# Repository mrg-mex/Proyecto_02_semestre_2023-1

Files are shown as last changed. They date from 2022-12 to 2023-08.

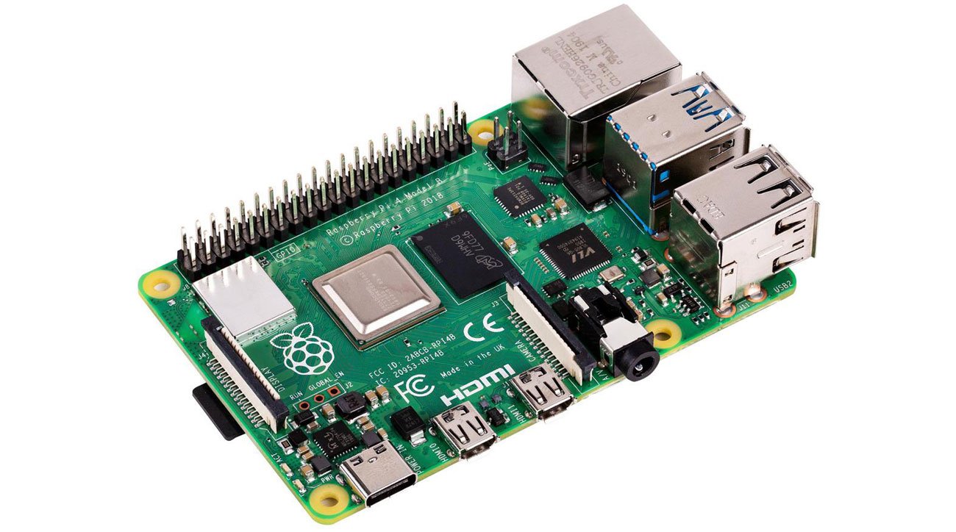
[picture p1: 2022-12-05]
CAD/Raspberry/Raspberry_Pi_4_model_B_widok_ogolny_1.jpg

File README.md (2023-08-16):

# Proyecto_2_semestre_2023-1
# Revisión, rediseño e implementación de un robot móvil Rasbot UNAM

# Participantes
- Erik Peña Medina (responable).
- Rojas Trejo Sebastián (participante)
- Luis García Mejía (participante)
- Andrés David Flores Ferro (participante)
- Alvarado Rivera Daniela (Participante, Semestre 2023-2)
- García Ávila Angel Alberto (Participante, Semestre 2023-2)
- Rios Torres Brenda (Participante, Semestre 2023-2)

# Contenido
- [Objetivo](https://github.com/mrg-mex/Proyecto_02_semestre_2023-1/blob/main/README.md#objetivo)
- [Metas](https://github.com/mrg-mex/Proyecto_02_semestre_2023-1/blob/main/README.md#metas)
- [Productos](https://github.com/mrg-mex/Proyecto_02_semestre_2023-1/blob/main/README.md#productos)
- [Introducción](https://github.com/mrg-mex/Proyecto_02_semestre_2023-1/blob/main/README.md#introducci%C3%B3n)
- [Desarrollo](https://github.com/mrg-mex/Proyecto_02_semestre_2023-1/blob/main/README.md#desarrollo)
- [Conclusión](https://github.com/mrg-mex/Proyecto_02_semestre_2023-1/blob/main/README.md#conclusi%C3%B3n)

# Objetivo

Implementar un robot móvil (2,0) el cual podrá ser utilizado para la programación de algoritmos de navegación mediante el uso de sensores ultrasónicos y análisis de imágenes.

# Metas

-	Evaluar y rediseñar el diseño del robot móvil con el fin de incorporar un par de sensores ultrasónicos y el controlador de los motores.
-	Desarrollar una simulación del robot móvil Gazebo como herramienta de integración en ROS2.
-	Implementar los resultados de la simulación en un ambiente físico definido para los robots.

# Productos

- Un banco de pruebas virtual en el cual se pueden programar diferentes algoritmos de navegación en el robot móvil. 
- Un banco de pruebas físico en el cual puedan ser implementados los algoritmos comprobados en el banco de pruebas virtual.
- Un repositorio con todos los archivos generados durante el desarrollo del proyecto.
- Circuito físico del sensor HY-SRF05
-	Circuito físico de dos motorreductores controlados con un controlador
-	Cámara Raspberry Pi NoIR Camera V2 funcionando adecuadamente

# Introducción
El desarrollo de los robots móviles ocurre debido a la necesidad de realizar cierto tipo de movimientos en ambientes determinados, de los cuales se desea obtener información mediante sensores que ayuden a medir las variables de interés (distancia, velocidad, humedad, etc.).

Ante la emergencia sanitaria que se vivió en el año 2020 (COVID 19), la robótica móvil comenzó a desarrollarse aún más, esto, debido a que era necesario reducir el contacto humano. Un gran ejemplo de esto ocurrió en la clínica Victoria de Medellín ubicada en Colombia, en donde se implementó un robot móvil para esterilizar espacios que habían sido contaminados de manera rápida y efectiva sin la necesidad de que hubiera contacto físico. En la India también se pudo observar que había robots móviles encargados de suministrar alimento y medicamentos a pacientes con COVID 19, esto ayudaba a minimizar el contagio, pues era como si los pacientes fuesen prácticamente independientes de otros seres humanos.

Lo anterior significa que existe un gran campo de aplicación de los robots móviles, e incluso hay necesidades que aún no están cubiertas porque no hay situación que lo amerite, pero la tecnología debe estar preparada para enfrentar cualquier situación que surja en el mundo.
Un robot móvil es capaz de moverse autónomamente y de ejecutar determinadas acciones. Junto a la movilidad, por tanto, la independencia del robot respecto de la intervención humana es uno de los aspectos esenciales de la robótica móvil.

La robótica móvil actualmente aún se encuentra en un estadio relativamente temprano de su desarrollo, hace varios años que se utilizan prototipos y productos en serie en diferentes sectores como en el transporte, la agricultura, vehículos autónomos, etc.

Algunas de las características que presenta la robótica móvil son:
- Percepción mediante sistemas sensores
- Capacidad de adaptación ante circunstancias espaciales modificadas
- Navegación, planificación y actuación autónomas
- Software/programación orientados a tareas 

Por medio de este documento se intenta plasmar algunas situaciones de diseños que se solucionaron en el robot raspbot como lo es el redimensionamiento de algunas piezas, la corrección de problemas al abrir archivos en solidworks, el diseño y ensamble de nuevas piezas, entre otras actividades que se especificaran en el documento.

Lo anterior se planteó solucionar mediante la separación de actividades usando issues y mediante el uso del programa solidworks y finalmente los resultados obtenidos se encuentran descritos a lo largo de documento.

# Desarrollo

Las problemáticas del robot móvil (2,0) comenzaron con la presencia de errores en los archivos Chasis_2-1 y Chaster_shorun_65-1 provenientes del ensamble CAD, siendo la pieza de chasis del robot y la pieza del sistema de rueda bola loca respectivamente. Por lo tanto este fue el primer problema que se atacó y por ende el primero que se resolvió, siendo de vital importancia para el correcto desarrollo del proyecto debido a que bajo éste ensamble y sus archivos, trabajaría todo el equipo.

Al tener un ensamble libre de errores, procedimos a identificar, estructurar, organizar y delimitar tareas por medio de problemáticas o issues usando GitHub como herramienta. Identificamos y propusimos en total seis problemas principales en cuanto a diseño se refiere:

- [Actividad 1: Arreglar archivos actuales que originan errores de ensamble.](https://github.com/mrg-mex/Proyecto_02_semestre_2023-1/issues/1)
- [Actividad 2: Diseño colocación del sistema de sensores ultrasónicos.](https://github.com/mrg-mex/Proyecto_02_semestre_2023-1/issues/2)
- [Actividad 3: Cambio diseño superior de robot móvil, NUEVO Ventilador para Raspberry.](https://github.com/mrg-mex/Proyecto_02_semestre_2023-1/issues/3)
- [Actividad 4: Modificaciones en chasis para problemáticas actuales.](https://github.com/mrg-mex/Proyecto_02_semestre_2023-1/issues/4)
- [Actividad 5: Detalles para base superior código QR.](https://github.com/mrg-mex/Proyecto_02_semestre_2023-1/issues/5)
- [Actividad 6: Recuperar diseño actual de pieza. Rueda bola loca.](https://github.com/mrg-mex/Proyecto_02_semestre_2023-1/issues/6)

En base a estas problemáticas y con la primera de ellas ya resuelta (arreglo de archivos) distribuimos las problemáticas entre los tres integrantes de este proyecto para así, lograr un mayor avance en la solución y conclusión de la lista de problemas; sin dejar de lado una comunicación entre los integrantes del equipo ante cualquier situación o solicitud de apoyo.

Para iniciar nuestras respectivas actividades, lo primero que se hizo fue analizar el robot móvil físicamente para anotar dimensiones, observar los elementos que los componen y su distribución, ver los espacios o secciones no aprovechadas en el chasis y su factibilidad de realizar modificaciones en ese espacio específico. Esto nos brindó mucha información en nuestra lluvia de ideas para lograr la solución más creativa y óptima. Asimismo, aprovechamos para tomar las medidas correctas principalmente de la rueda bola loca, siendo un proceso esencial en la actividad 6 para comparar las medidas reales con las medidas establecidas en el CAD y modificarlas a su valor real. De manera secundaria, se observó y midió el ventilador para la Raspberry con fines de lograr una eficaz modificación en la parte superior del robot. Finalmente pero no menos importante, se observó el modelo para obtener ideas acerca de la colocación de tres sensores ultrasónicos y el doble puente H que llevará el robot para el control de los dos motores CD.

Las modificaciones al chasis del robot móvil fueron una parte vital de nuestro proyecto, ya que ésta actividad tenía relación con la base superior, las conexiones con el microprocesador Raspberry y el doble puente H y la colocación de los sensores ultrasónicos, por ende, las primeras modificación que se hicieron fueron en beneficio de la óptima conexión entre la Raspberry y el doble puente H, y modificaciones para la colocación de la base superior.

Para la base superior, se modificaron los diámetros de los orificios donde se insertan los postes de latón que sujetan a la Raspberry y se extruyeron un par de milímnetros más para aumentar la altura de la base y así liberar la entrada micro SD. Para garantizar que el usuario que maneje el robot móvil no tenga problemas con la inserción y retiro de la micro SD, los orificios se separaron ligeramente de la base para la cámara.

Las siguientes modificaciones a trabajar fueron los elementos para la conexión del microcontrolador y el puente H. Dicha conexión se logró perforando en forma de ranura el lateral del chasis para que, de esta manera los cables que deriven de la Raspberry puedan pasar por esta ranura y no dificulte el desplazamiento del robot. Para la colocación del doble puente H se realizó una serie de canales o correderas, en donde se deslizará y sujetará el módulo con los pines disponibles para conexión. Como complemento, se realizó un arco en el lateral del chasis, cerca de la ranura con el fin de que por ahí pasen los cables de conexión y se contengan dentro del arco, evitando que los cables sobresalgan demasiado y estorben en su funcionamiento más de lo que ayudan.




La última modificación para el chasis dependía del diseño previo realizado para la colocación de los tres sensores ultrasónicos. Se llegó a un primer modelo, el cual, después de ser analizado y ensamblado a la estructura, se desechó debido al sesgo y posibles errores de sensado debido a la distribución propuesta.



Procedimos a realizar una segunda propuesta, donde dos de los sensores ultrasónicos estarán en la parte superior del chasis a los laterales y el tercero se encontrará enfrente de éste, en la parte inferior, haciendo analogía a una defensa de auto. La estructura para la colocación de los dos sensores laterales estará integradas directamente al chasis, mientras que el tercero se montará con ayuda de una pieza externa. Con estos requerimientos y consideraciones, procedimos a modificar el chasis con las operaciones oportunas para lograr el correcto ensamble y montaje de los tres sensores, solucionando así la actividad 2 y 4



Para la solución de la actividad 3 (el ventilador), se encontró un CAD existente con las dimensiones requeridas, se colocó en el CAD e implementaron restricciones para mantenerlo en el lugar adecuado dentro del archivo de ensamble y finalmente se modificó la base para lograr una disminución de espacio.



La actividad 5, al estar relacionada de igual manera con la base (la cual fue modificada en la actividad 3), logró solucionarse de una manera más sencilla con el acomodo del ventilador y la base del código QR.



Para la actividad 6 bastó con modificar los elementos que componían la rueda bola loca y ajustarlos a las medidas reales realizadas en el laboratorio.



De esta forma se concluyeron exitosamente las actividades propuestas al inicio del proyecto, logrando obtener un archivo ensamble completo, que inmediatamente se mandó a imprimir para observar y probar los resultados finales de nuestro trabajo. Sin embargo, esto no fue posible debido a un problema con la boquilla en la impresora 3D, dificultando la salida del material para la fabricación el chasis. 

Finalmente se decidió que la mejor solución será cambiar la boquilla por una nueva y mandar el archivo nuevamente a impresión.

Se anexa una fotografía de la impresión resultante antes de que la impresora sufriera este percance.




El robot móvil RaspBot se presentó con los sensores acoplados al chasis, sin embargo, estos aún no eran funcionales, por ende, se comenzó a explorar el robot y ver que sensores debían tener funcionamiento, estos fueron:
- Sensor ultrasónico HY-SRF05 (3)
- Motorreductor recto acoplado a una llanta (2)
- Cámara Raspberry Pi NoIR
  
Para poder realizar la programación, se hizo uso de:
- Raspberry pi 4
- Motor Driver TB6612FNG
- Herramienta computacional Thonny
  
Se inició con la activación de los motorreductores mediante la implementación del siguiente circuito:

# Avavces del semnestre 2023-2

Objetivo
Implementar un robot móvil (2,0) el cual podrá ser utilizado para la programación de algoritmos de navegación mediante el uso de sensores ultrasónicos y análisis de imágenes. 
Metas
•	Evaluar y rediseñar el diseño del robot móvil con el fin de incorporar un par de sensores ultrasónicos y el driver de control de los motores.
•	Desarrollar de una simulación del robot móvil en el simulador Gazebo mediante su implementación en ROS2.
•	Implementar los resultados de la simulación en un ambiente definido para los robots.
Productos
 	Circuito físico del sensor HY-SRF05
 	Circuito físico de dos motorreductores controlados con un driver
 	Cámara Raspberry Pi NoIR Camera V2 funcionando adecuadamente

## Introducción 
El desarrollo de los robots móviles ocurre debido a la necesidad de realizar cierto tipo de movimientos en ambientes determinados, de los cuales se desea obtener información mediante sensores que ayuden a medir las variables de interés (distancia, velocidad, humedad, etc.).
Ante la emergencia sanitaria que se vivió en el año 2020 (COVID 19), la robótica móvil comenzó a desarrollarse aún más, esto, debido a que era necesario reducir el contacto humano. Un gran ejemplo de esto ocurrió en la clínica Victoria de Medellín ubicada en Colombia, en donde se implementó un robot móvil para esterilizar espacios que habían sido contaminados de manera rápida y efectiva sin la necesidad de que hubiera contacto físico. En la India también se pudo observar que había robots móviles encargados de suministrar alimento y medicamentos a pacientes con COVID 19, esto ayudaba a minimizar el contagio, pues era como si los pacientes fuesen prácticamente independientes de otros seres humanos.
Lo anterior significa que existe un gran campo de aplicación de los robots móviles, e incluso hay necesidades que aún no están cubiertas porque no hay situación que lo amerite, pero la tecnología debe estar preparada para enfrentar cualquier situación que surja en el mundo.

## Desarrollo

El robot móvil RaspBot se nos presentó con los sensores acoplados al chasis, sin embargo, estos aún no eran funcionales, por ende, se comenzó a explorar el robot y ver que sensores debían tener funcionamiento, estos fueron:
- Sensor ultrasónico HY-SRF05 (3)
- Motorreductor recto acoplado a una llanta (2)
- Cámara Raspberry Pi NoIR
Para poder realizar la programación, se hizo uso de:
- Raspberry pi 4
- Motor Driver TB6612FNG
- Herramienta computacional Thonny 

Se inició con la activación de los motorreductores mediante la implementación del siguiente circuito:

# Conclusión

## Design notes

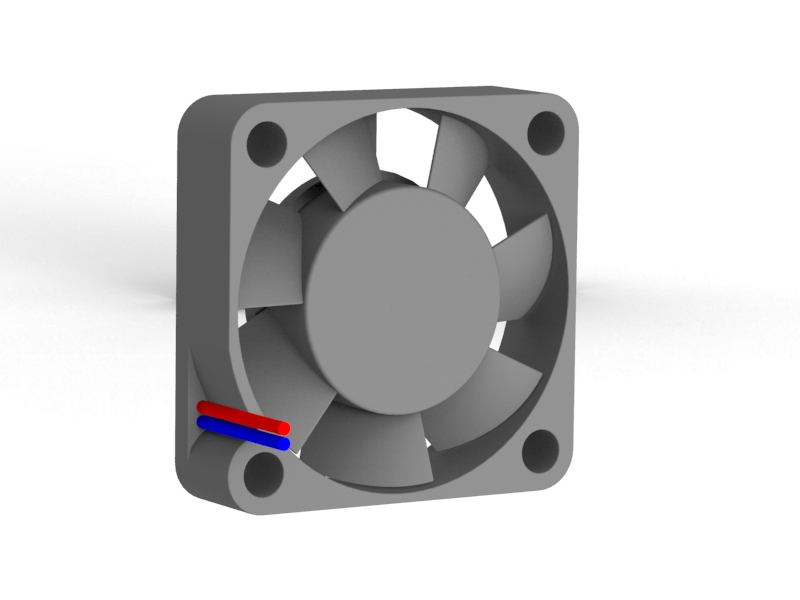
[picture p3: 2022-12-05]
CAD/Fan_30x30x8_5V_2pin.jpg

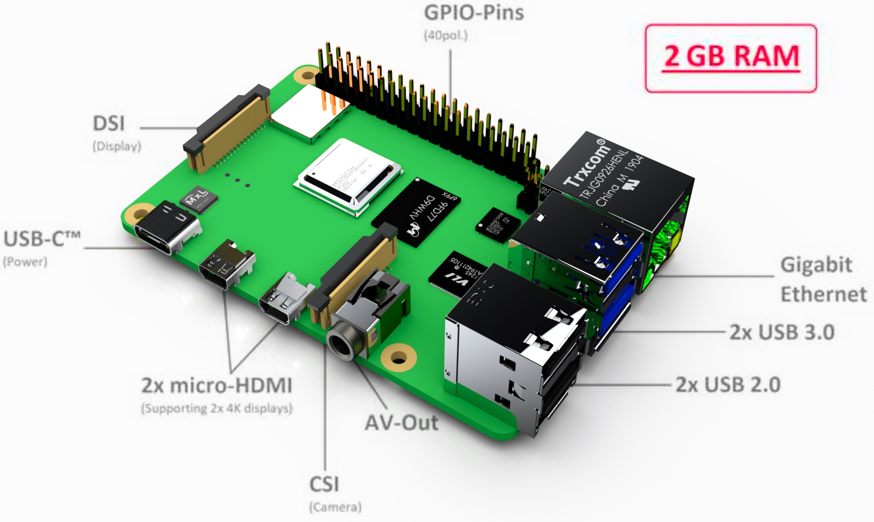
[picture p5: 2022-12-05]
CAD/Raspberry p4 4.jpg

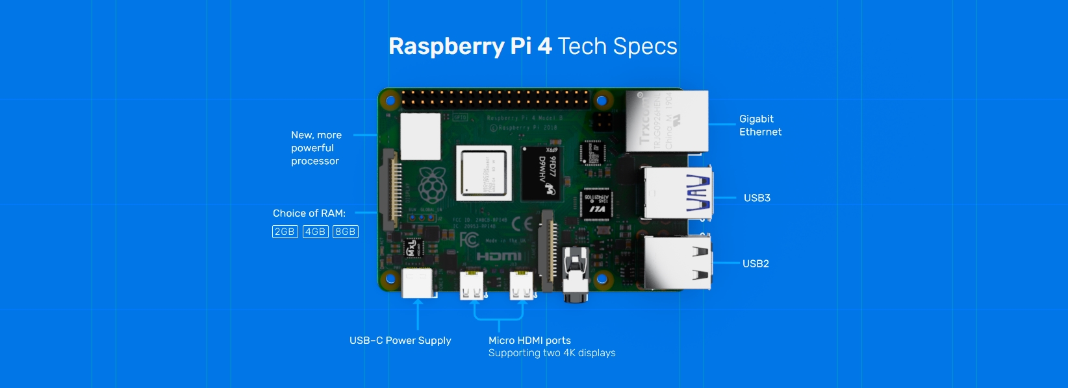
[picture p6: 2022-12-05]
CAD/Raspberry/Raspberry p4 v1.jpg

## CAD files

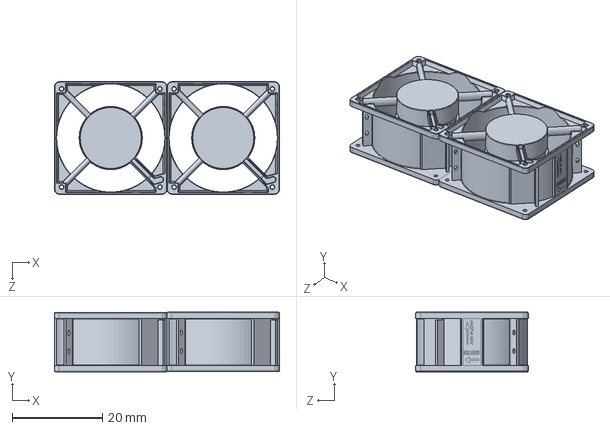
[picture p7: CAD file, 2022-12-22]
CAD/VENTILADOR2.0.SLDASM
50.0 x 13.2 x 25.0 mm
VENTLADOR2.0 x 2

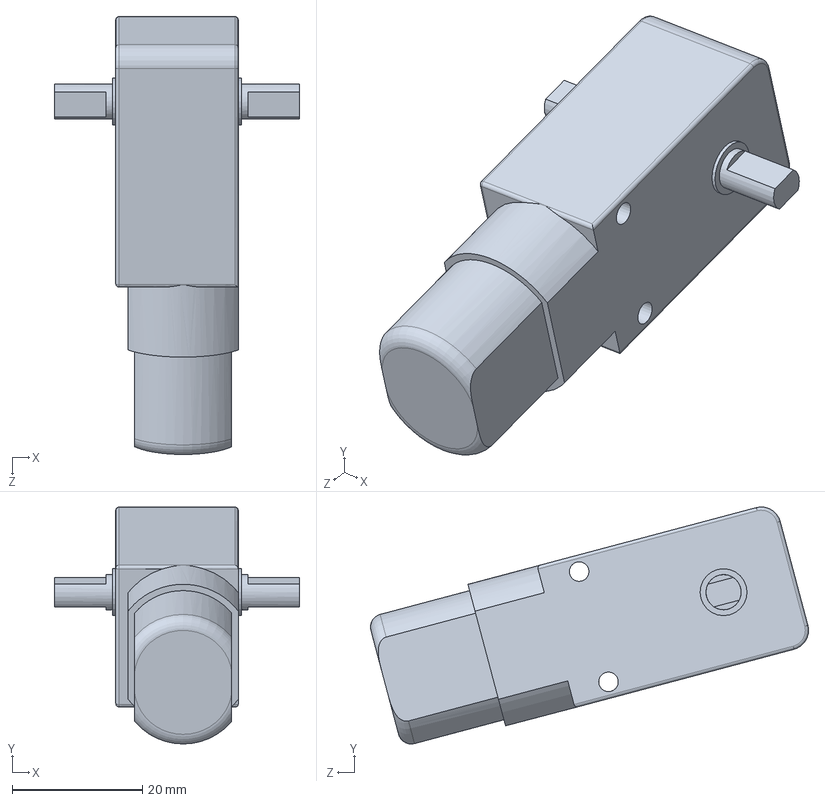
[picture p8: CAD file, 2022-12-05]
CAD/dc_motor_and_wheel_1.SLDASM
37.6 x 36.4 x 67.2 mm

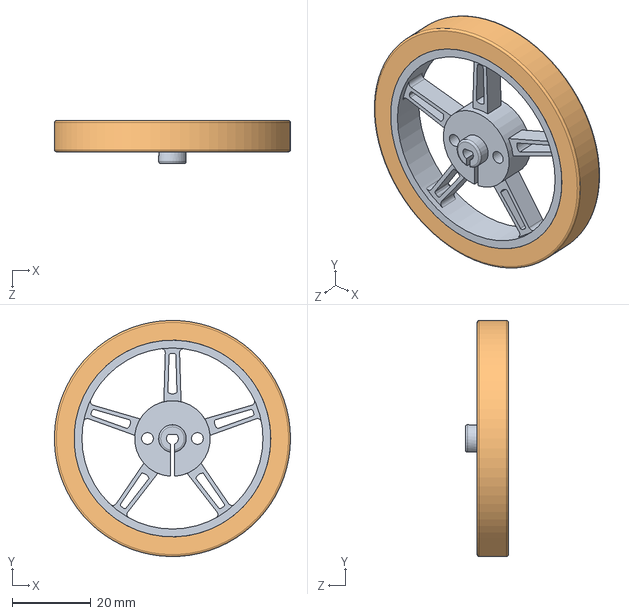
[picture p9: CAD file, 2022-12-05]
CAD/PololuWheel 60x8mm.SLDASM
60.0 x 60.0 x 11.0 mm
Part2^PololuWheel 60x8mm
Part3^PololuWheel 60x8mm

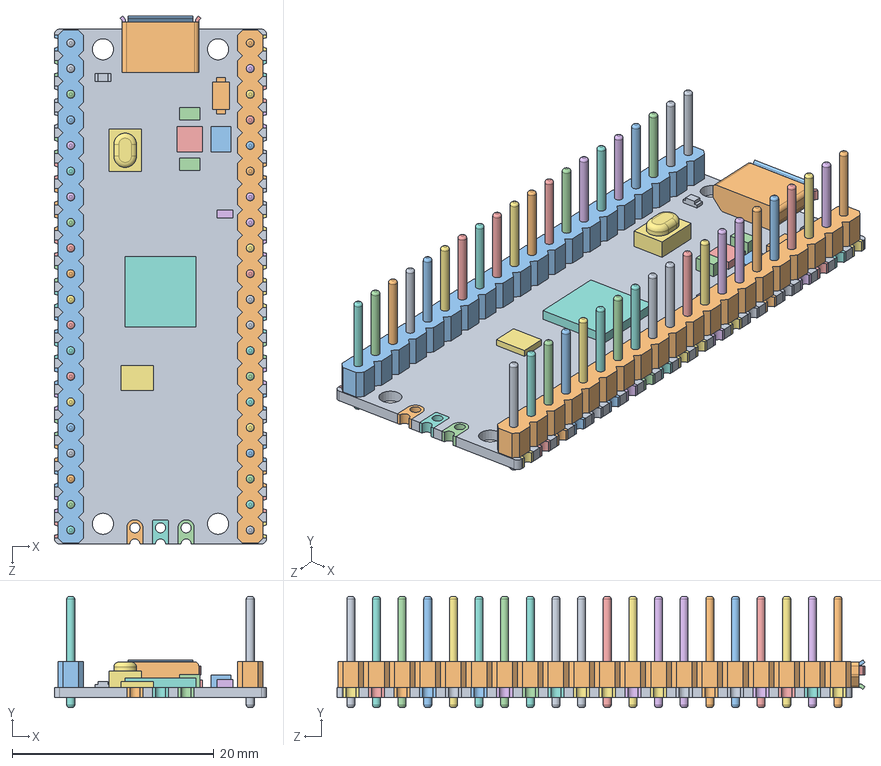
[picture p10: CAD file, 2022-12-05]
CAD/PICO_PINS_UP/PICO_PinsUp.SLDASM
21.0 x 11.0 x 52.3 mm
PICO_REF_BOARD.STEP
PICO_REF_USB.STEP_4
PICO_REF_USB.STEP_5
PICO_REF_USB.STEP
PICO_REF_USB.STEP_2
PICO_REF_USB.STEP_3
PICO_REF_SWITCH.STEP
PICO_REF_MICROCONTROLLER.STEP
PICO_REF_LED.STEP
PICO_REF_ONSEMI.STEP
PICO_BOURNS.STEP
PICO_MURATA.STEP x 2
PICO_RICHTEK.STEP
PICO_DIODES.STEP
PICO_AEL.STEP
PICO_PIN_HEADERS_40
PICO_PIN_HEADERS_7
PICO_PIN_HEADERS_6
PICO_PIN_HEADERS_11
PICO_PIN_HEADERS_30
PICO_PIN_HEADERS_23
PICO_PIN_HEADERS_28
PICO_PIN_HEADERS_12
PICO_PIN_HEADERS_18
PICO_PIN_HEADERS_33
PICO_PIN_HEADERS_41
PICO_PIN_HEADERS_20
PICO_PIN_HEADERS_42
PICO_PIN_HEADERS_39
PICO_PIN_HEADERS_35
PICO_PIN_HEADERS_2
PICO_PIN_HEADERS_13
PICO_PIN_HEADERS_24
PICO_PIN_HEADERS_29
PICO_PIN_HEADERS_14
PICO_PIN_HEADERS_21
PICO_PIN_HEADERS_9
PICO_PIN_HEADERS_10
PICO_PIN_HEADERS_31
PICO_PIN_HEADERS_17
PICO_PIN_HEADERS_4
PICO_PIN_HEADERS
PICO_PIN_HEADERS_5
PICO_PIN_HEADERS_15
PICO_PIN_HEADERS_16
PICO_PIN_HEADERS_19
PICO_PIN_HEADERS_32
PICO_PIN_HEADERS_34
PICO_PIN_HEADERS_3
PICO_PIN_HEADERS_36
PICO_PIN_HEADERS_22
PICO_PIN_HEADERS_37
PICO_PIN_HEADERS_26
PICO_PIN_HEADERS_25
PICO_PIN_HEADERS_38
PICO_PIN_HEADERS_27
PICO_PIN_HEADERS_8
PICO_HEADER_HOLES_16
PICO_HEADER_HOLES_18
PICO_HEADER_HOLES_31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

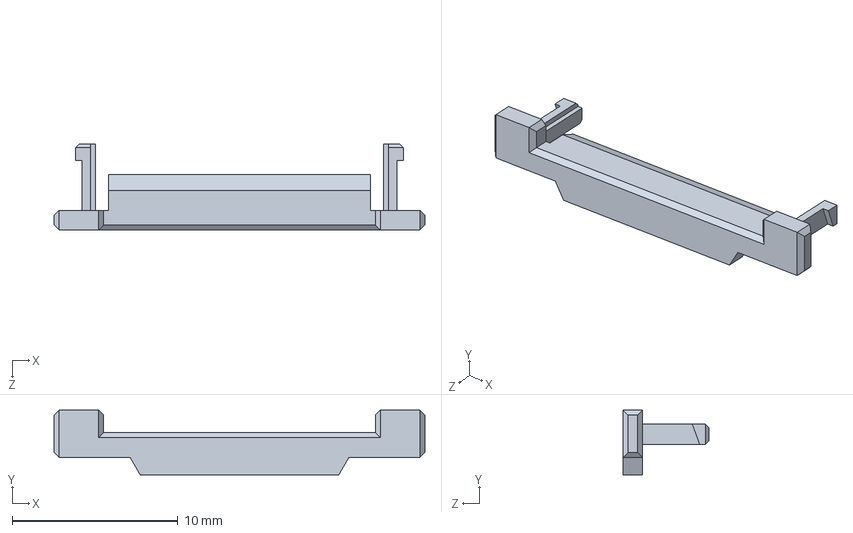
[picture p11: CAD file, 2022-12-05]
CAD/Raspberry/1. display connector assembly/3.3 plastic.SLDPRT
22.4 x 3.90 x 5.18 mm

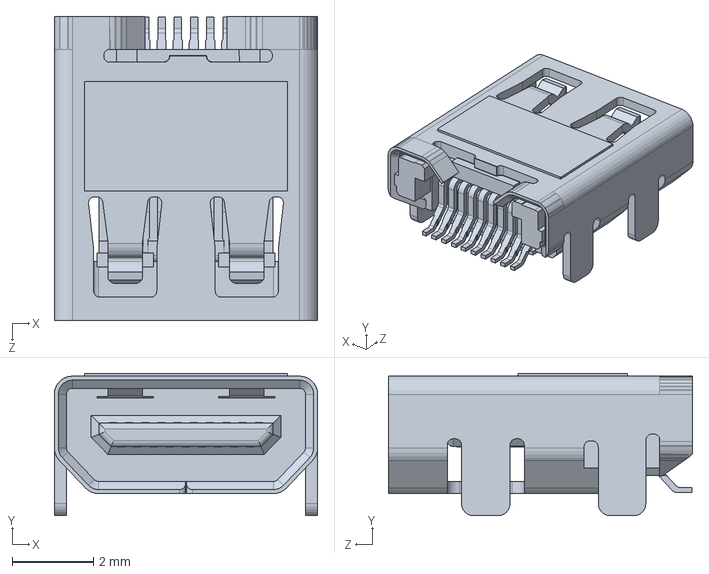
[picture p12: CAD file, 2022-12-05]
CAD/Raspberry/11.0 Female micro HDMI connector.SLDPRT
6.50 x 3.52 x 7.50 mm

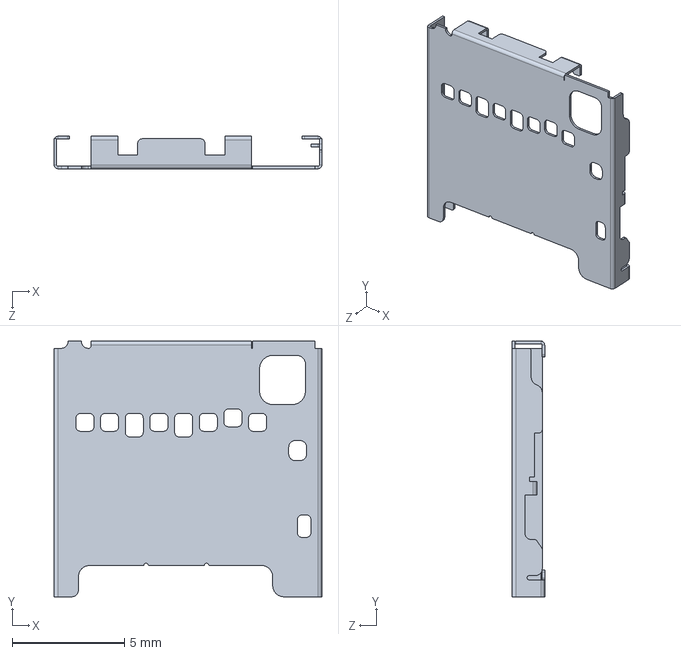
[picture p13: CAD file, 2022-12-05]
CAD/Raspberry/2. card slot/part 3 v1.SLDPRT
11.9 x 11.4 x 1.45 mm

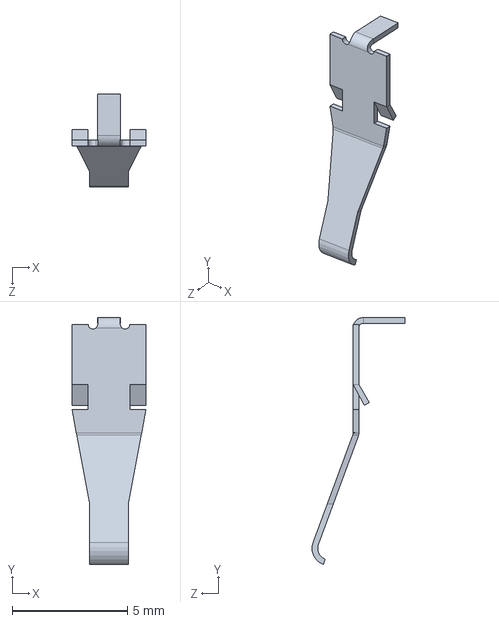
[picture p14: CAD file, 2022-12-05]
CAD/Raspberry/Microphone plug/part 3 microphone plug.SLDPRT
3.20 x 10.7 x 4.03 mm

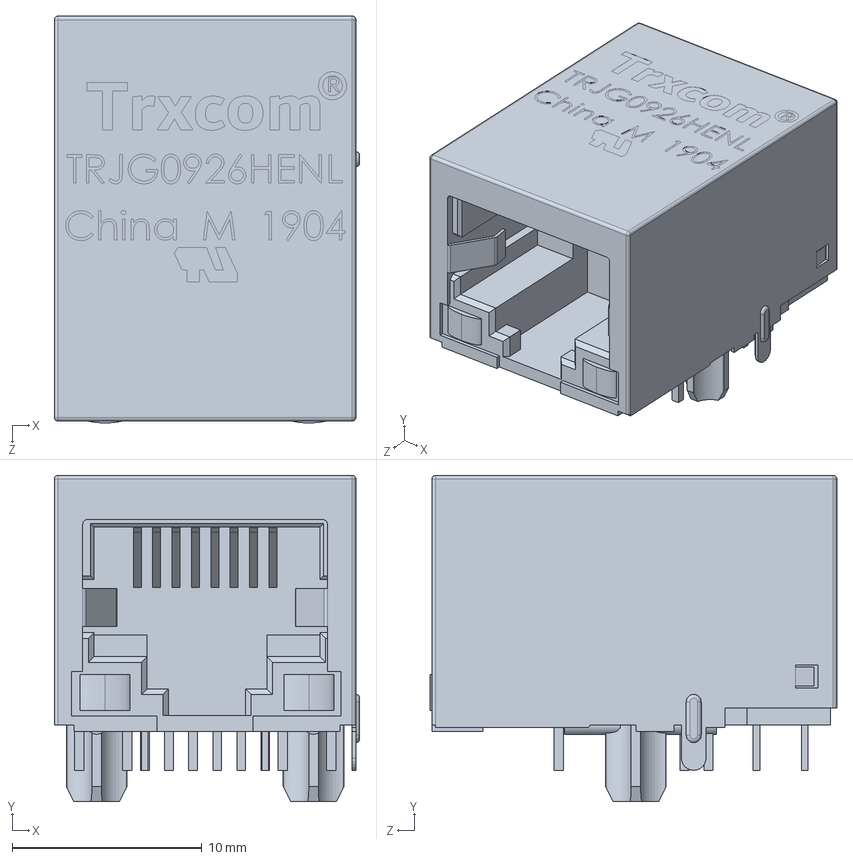
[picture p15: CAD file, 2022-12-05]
CAD/Raspberry/Microphone plug/part/12.0 Gigabit ethernet port raspberry.SLDPRT
16.1 x 17.2 x 21.4 mm

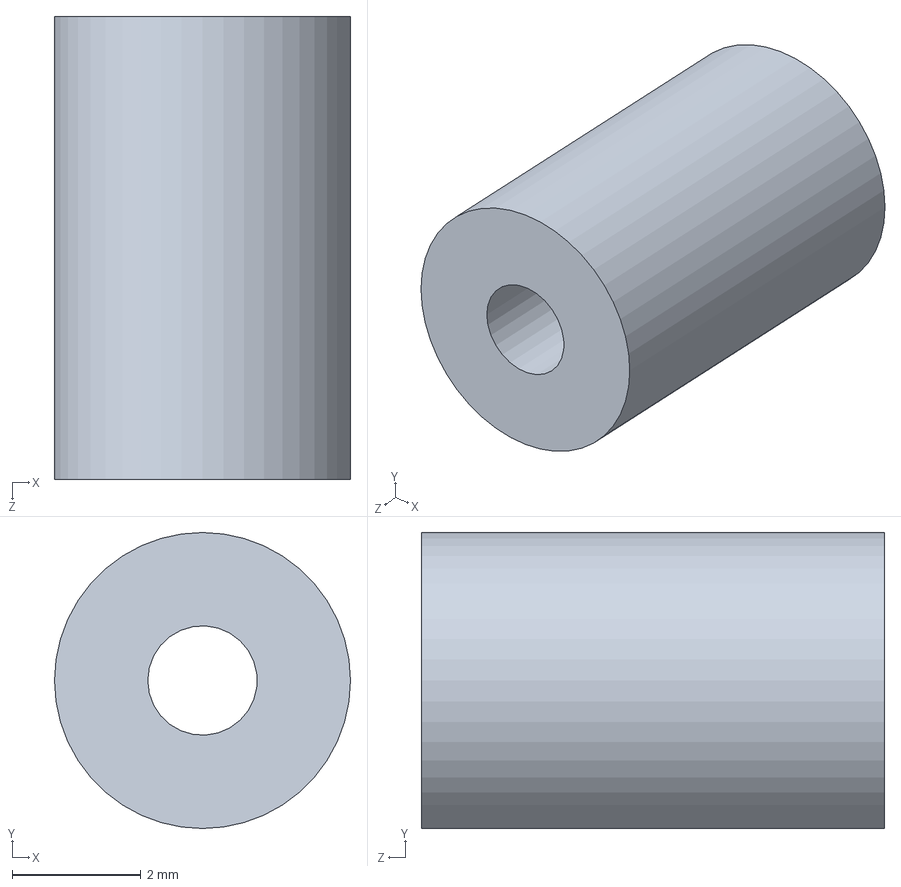
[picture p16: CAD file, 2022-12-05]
CAD/sg90-micro-servomotor-1.snapshot.2/Part2.SLDPRT
4.60 x 4.60 x 7.20 mm

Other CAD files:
CAD/PICO_PINS_UP/PICO_REF_USB.STEP.SLDASM
CAD/PICO_PINS_UP/PICO_PIN_HEADERS.SLDASM
CAD/PICO_PINS_UP/PICO_HEADER_HOLES.SLDASM
CAD/PICO_PINS_UP/PICO_HEADER_HOLES_12.SLDPRT
CAD/Agarradera.SLDPRT
CAD/AprilTag.SLDPRT
CAD/Arducam16MPCamera.SLDPRT
CAD/Ball_2_5.SLDPRT
CAD/Base_cam.SLDPRT
CAD/Body.SLDPRT
CAD/Body_cam.SLDPRT
CAD/Cam_servo.SLDPRT
CAD/Caster_base_65.SLDPRT
CAD/Caster_shroun_65.SLDPRT
CAD/Fan_30x30x8_5V_2pin.SLDASM
CAD/Fan_30x30x8_5V_2pin.SLDPRT
CAD/Fan_30x30x8_5V_2pin.stp
CAD/Llanta_pololu.SLDPRT
CAD/PICO_PINS_UP/PICO_AEL.STEP.SLDPRT
CAD/PICO_PINS_UP/PICO_BOURNS.STEP.SLDPRT
CAD/PICO_PINS_UP/PICO_DIODES.STEP.SLDPRT
CAD/PICO_PINS_UP/PICO_HEADER_HOLES.SLDPRT
CAD/PICO_PINS_UP/PICO_HEADER_HOLES_10.SLDPRT
CAD/PICO_PINS_UP/PICO_HEADER_HOLES_11.SLDPRT
CAD/PICO_PINS_UP/PICO_HEADER_HOLES_13.SLDPRT
CAD/PICO_PINS_UP/PICO_HEADER_HOLES_14.SLDPRT
CAD/PICO_PINS_UP/PICO_HEADER_HOLES_15.SLDPRT
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

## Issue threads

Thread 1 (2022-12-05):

Actividad 1: Arreglar archivos actuales que originan errores de ensamble

AndresFloresF, 2022-12-05:
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
Al abrir el ensamble se identificaron errores en 2 archivos
Chasis_2-1 , pieza de chasis del robot
Chaster_shorun_65-1, pieza del sistema de rueda bola loca

AndresFloresF, 2022-12-05:
Correcciones realizadas en los archivos:
Chasis_2.SLDPRT , relación a simetría perdida.
Chaster_shorun_65.SLDPRT, sobredimensionamiento de pieza.

AndresFloresF, 2022-12-05:
Modificaciones realizadas al abrir Ensamble.

Problema resuelto.
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

AndresFloresF, 2022-12-05:
Modificaciones realizadas al abrir Ensamble.

Problema resuelto.
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

Closed 2022-12-05.

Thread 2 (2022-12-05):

Actividad 2: Diseño colocación del sistema de sensores ultrasónicos.

AndresFloresF, 2022-12-05:
Actividades propuestas para resolver la problemática:

1. Buscar CAD de sensor ultrasónico para dimensionar con respecto al robot móvil.
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
2. Observar que se requiere para poder colocar tres sensores ultrasónicos integrado al chasis o en un extra al chasis.

3. Primer diseño de base para ultrasónicos, dentro de chasis o en pieza extra.

AndresFloresF, 2022-12-06:
Actividad 1 Resuelta, ya se cuenta con el archivo CAD
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
Archivo:  hc sr04 ultrasonic sensor.SLDPRT

AndresFloresF, 2022-12-06:
Actividad 2 a medias, revisar resto de consideraciones:

Altura chasis robot en la parte inferior: 25 mm
Altura sensor ultrasónico colocado horizontalmente: 21 mm
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

AndresFloresF, 2022-12-21:
![PrimerPropuesta](https://user-images.githubusercontent.co
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
m/42392795/208817396-12989110-2580-462c-a320-5cd41e07b736.jpg)
Primer propuesta, ultrasónicos, verificando si es posible colocar en ensamble y como

SebassBv, 2022-12-22:
Se propuso una nueva distribución de los sensores ultrasónicos. Se añadieron ganchos a la estructura del sensor forntal y se modificó el chasis para la colocación de los sensores laterales

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

AndresFloresF, 2022-12-22:
Chasis y distribución en espera de aprobación por parte del maestro, se puede imprimir el diseño actual de chasis v2 acorde al equipo de trabajo @ErikFiUNAM
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

ErikFiUNAM, 2022-12-22:
Deje imprimiendo el Chasis para hacer pruebas con el ensamble, la siguiente
semana regresó para ver como quedó. Cualquier cosa les aviso.

Atte. M.I. Erik Peña Medina.

El jue, 22 dic 2022 a la(s) 00:52, Andres Flores ***@***.***)
escribió:

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

Closed 2022-12-22.

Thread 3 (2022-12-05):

Actividad 3: Cambio diseño superior de robot móvil, NUEVO Ventilador para Raspberry

AndresFloresF, 2022-12-05:
Actividades propuestas para resolver la problemática:
1.  Buscar o realizar modelo CAD de ventilador mini para Raspberry.
(Posiblemente tomar medidas del ventilador, buscar o diseñar, para tenerlo en CAD)
2. Revisar y eliminar consideraciones actuales del ventilador en la parte superior (ya señaladas en la imagen)
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
3. Colocar en ensamble  en su posición, considerando como se colocará, y que permita conocer la altura para el diseño de la actividad 5.  [https://github.com/mrg-mex/Proyecto_02_semestre_2023-1/issues/5](url)

GarciaMejiaLuis, 2022-12-21:
Para el modelo CAD del ventilador dual mini para raspberry se uso el modelo CAD de otro ventilador similar, se ajusto sus medidas a la del ventilador RaspBerry.
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

Al duplicarlo y ponerles restricciones de ensamble se obtuvo lo siguiente.
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
Ventilador Original
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

GarciaMejiaLuis, 2022-12-23:
Se acomodo el ventilador en el CAD y se coloco restricciones de posición en el mismo para fijarlo en una ubicación.
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

Por otro lado se modifico la antigua base del ventilador para que ocupe el menor espacio posible.
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

El resultado final fue el siguiente
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

Closed 2022-12-23.

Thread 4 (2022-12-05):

Actividad 4: Modificaciones en chasis para problemáticas actuales.

AndresFloresF, 2022-12-05:
Actividades a realizar en esta parte :

PARTE SUPERIOR:
Editar chasis para liberar la entrada MicroSD de la raspberry
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

Arreglar orificios para postes de latón que sujeten la raspberry.
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

PARTE INFERIOR:
- Colocación de posible PCB para los puente H en la parte inferior del robot, antes de sujetadores de encoder.
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
- Dar una solución para pasar cables de la parte superior a la inferior y conectar los componentes actuales (ultrasónicos, puente H, motores a donde correspondan)

SebassBv, 2022-12-14:
PARTE SUPERIOR

Se modificó el diámetro del agujero para los postes de latón. Se probarán 3 medidas: 2.6 mm, 2.7 mmm y 2.65 mm para ver cual diámetro es el más justo para los postes.

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

SebassBv, 2022-12-14:
PARTE SUPERIOR

Se modificó el chasis, principalmente el croquis que contiene las extrusiones de los orificios para liberar el puerto de entrada microSD, la estructura se desplazó más lejos de la baseCam y se extruyeron ligeramente los soportes para lograr dicha liberación

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

SebassBv, 2022-12-15:
PARTE INFERIOR

Se agregó un nuevo componente llamado "agarradera" para lograr la contención y guía de los cables que conectarán la Rasperry y el doble puente H, además se agregó una ranura para que puedan pasar con mayor facilidad las conexiones sin afectar el funcionamiento del robot.

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

SebassBv, 2022-12-15:
PARTE INFERIOR

Se añadió el soporte que contendrá el puente H por debajo del Raspbot.

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

AndresFloresF, 2022-12-21:
Chasis en espera de sistema para colocar ultrasónicos, cambios agregados a rama principal

SebassBv, 2022-12-22:
Ranuración del chasis para la colocación del sensor ultrasónico frontal y moficiación de éste en la parte superior para colocación de los laterales

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

AndresFloresF, 2022-12-22:
Se considera que no existan mas cambios en chasis, por el momento se concluye la actividad 4.

Closed 2022-12-22.

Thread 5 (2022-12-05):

Actividad 5: Detalles para base superior código QR.

AndresFloresF, 2022-12-05:
Actividades propuestas para resolver la problemática:

1. Plantear en base a las modificaciones realizadas en chasis y ventilador, la altura y sistema de colocación para el código QR.
(Venir al laboratorio y observar ejemplos).
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

Problemática encontrada: Se deben completar las modificaciones anteriores para intentar dar una solución por las variaciones que darán:
- Actividad 3 [https://github.com/mrg-mex/Proyecto_02_semestre_2023-1/issues/4](url)
- Actividad 4 [https://github.com/mrg-mex/Proyecto_02_semestre_2023-1/issues/4](url)

GarciaMejiaLuis, 2023-01-05:
#13

AndresFloresF, 2023-01-07:
Modificaciones en CAD concluidas, en espera de resultados de impresion 3D.

Closed 2023-01-07.

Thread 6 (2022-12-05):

Actividad 6: Recuperar diseño actual de pieza. Rueda bola loca.

AndresFloresF, 2022-12-05:
Actividades propuestas para resolver la problemática:

1. Medir y obtener pieza impresa del sistema rueda bola loca del robot.
2. Observar diferencias entre CAD y medidas de pieza física.
3. Realizar modificaciones en la pieza correspondiente.

GarciaMejiaLuis, 2022-12-05:
Actividad 1. Medir y obtener las medidas de la pieza impresa del sistema de rodamiento del robot

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

AndresFloresF, 2022-12-22:
**DIFERENCIAS DETECTADAS ENTRE CAD Y PIEZA REAL CON MODIFICACIONES A REALIZAR.**
- Cambio de altura de 30mm a 26.5 mm , para tener mayor aproximación al valor medido (28.83 mm)
- Reducción de radio inferior de 15.25 mm a 13 mm , para corresponder al diámetro medido de 26 mm
- Cambio de espesor de 3 mm a 2.5 mm por la medida real de 2.4 mm, considerando 1mm de tolerancia para impresión.
- Radio Superior, cambio de ubicación de cota a vértice previo al arco, valor de 9.85, modificado a para obtener un radio similar al obtenido de 12.4 mm , nuevo valor de 12.5 mm con interior de 10 mm mas 2.5 mm de borde, 12.5 mm .
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

- Cambio de diámetro interior pieza de 2.5 mm a 2.3 mm , cercano al 2.2 mm de medida real.
- Sin modificaciones en distancia de circulo interior de pieza por dificultad de obtener la medida.
Aumento de espesor de extrusión a piezas de 2mm a 2.6 mm, cercano al 2.54 mm de medida real.
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
- Rediseño de soportes triangulares para piezas con 15.5 mm de altura.
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

AndresFloresF, 2022-12-22:
Se decidió retornar algunos cambios como lo fue la altura y el radio interior y exterior de la pieza, al tener complicaciones en el ensamble  y se podía observar que requería mas altura en comparación de las llantas.
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

Ahora bien, se realizo pequeñas modificaciones en la ubicación de orificios del chasis, menor a 2 mm de cada modificación.
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

Closed 2022-12-22.

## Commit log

2022-12-05 CAD proporcionado por maestro
    [1.0 Plate raspberry Pi 4.SLDPRT, 1.1 part 1 metal pin.SLDPRT, 10.0 Female USB connector.SLDPRT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]
2022-12-05 Corrigiendo piezas y Ensamble
    [Caster_shroun_65.SLDPRT]
2022-12-14 Modificación orificio y liberación de microSD
2022-12-15 Agarradera y ranura conexion Rasp-puenteH
    [Agarradera.SLDPRT]
2022-12-15 Soporte para puenteH
    [SoportePuenteH.SLDPRT]
2022-12-21 Primer Diseño Base Ultrasonicos
2022-12-22 Agregar ultrasonicos a carpeta
    [UltrasonicoSolo.SLDPRT, hc sr04 ultrasonic sensor.SLDPRT]
2022-12-22 Piezas Ultrasonico modificadas
    [UltrasonicoSolo.SLDPRT, UltrasonicoSoloFrontal.SLDPRT]
2022-12-22 Ranuras Ultrasonico
2022-12-22 Ultimos detalles ensamble ultrasónicos
    [UltrasonicoSolo.SLDPRT, UltrasonicoSoloFrontal.SLDPRT]
2022-12-22 Modificaciones pieza bola loca terminadas
    [Caster_shroun_65.SLDPRT]
2022-12-22 ventilador 2.0
    [VENTILADOR2.0.SLDASM]
2022-12-23 Add files via upload
    Agregando ensamble del ventilador con los archivos antes subidos del chasis y con el sensor ultrasonico
2023-01-16 Update README.md
    Corrección de ortografía en Desarrollo
2023-06-21 Create PWM
2023-08-16 Update README.md
    Actaulización del semestre 2023-2. imagenes y circuitos.
